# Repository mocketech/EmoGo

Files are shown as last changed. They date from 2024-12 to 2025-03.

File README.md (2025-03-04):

# EmoGo
A Go game system that conveys the state of Go stones through facial expressions

概要は以下の記事をご覧下さい。

Protopedia: [情碁 - 碁石の状態を表情で伝える囲碁ゲームシステム](https://protopedia.net/prototype/6237)

You can refer the following sites:
* Qiita: [XIAO RP2040でXIAO Round Displayを使う](https://qiita.com/mocketech/items/0c186354648cb941cb2cl) (in Japanese)
* [Seeed Studio XIAO RP2040 with Arduino](https://wiki.seeedstudio.com/XIAO-RP2040-with-Arduino/)
* [Getting Started with Seeed Studio Round Display for XIAO](https://wiki.seeedstudio.com/get_start_round_display/)
* Github: [MCP_CAN_lib](https://github.com/coryjfowler/MCP_CAN_lib)
* Waveshare: [2-CH CAN HAT](https://www.waveshare.com/wiki/2-CH_CAN_HAT)

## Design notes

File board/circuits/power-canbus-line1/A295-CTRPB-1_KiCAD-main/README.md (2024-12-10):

# A295-CTRPB-1_KiCAD
KiCAD library for A295-CTRPB-1

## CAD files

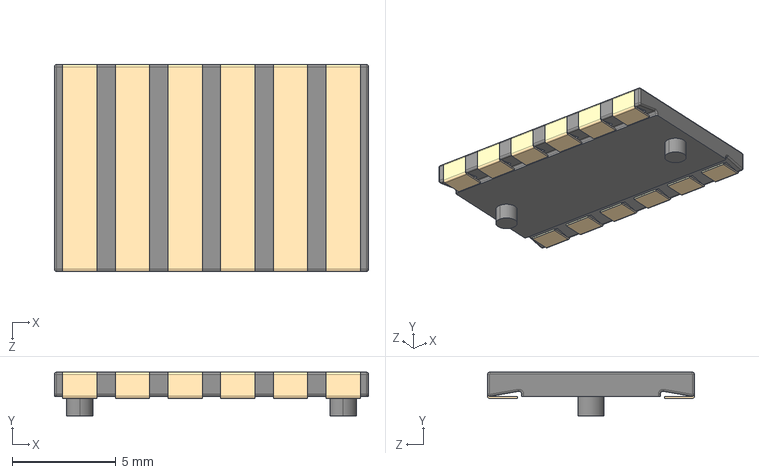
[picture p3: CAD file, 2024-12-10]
board/circuits/board/70AAJ-6-F1G/70AAJ-6-F1G.step
15.1 x 2.11 x 10.0 mm

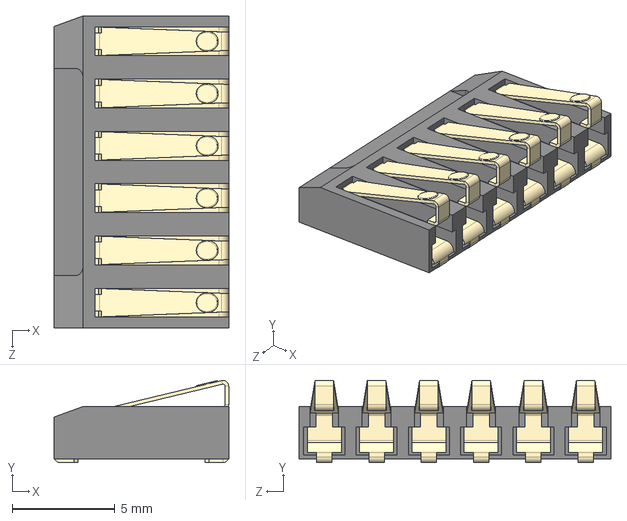
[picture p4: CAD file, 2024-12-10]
board/circuits/board/70AAJ-6-M0G/70AAJ-6-M0G.step
8.48 x 3.99 x 15.2 mm

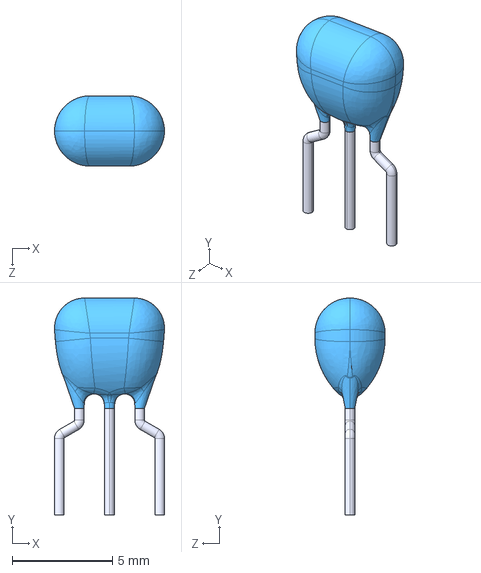
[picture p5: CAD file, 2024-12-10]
board/circuits/board/CSTLS20M0X51-B0/CSTLS20M0X51-B0.step
5.48 x 10.8 x 3.50 mm

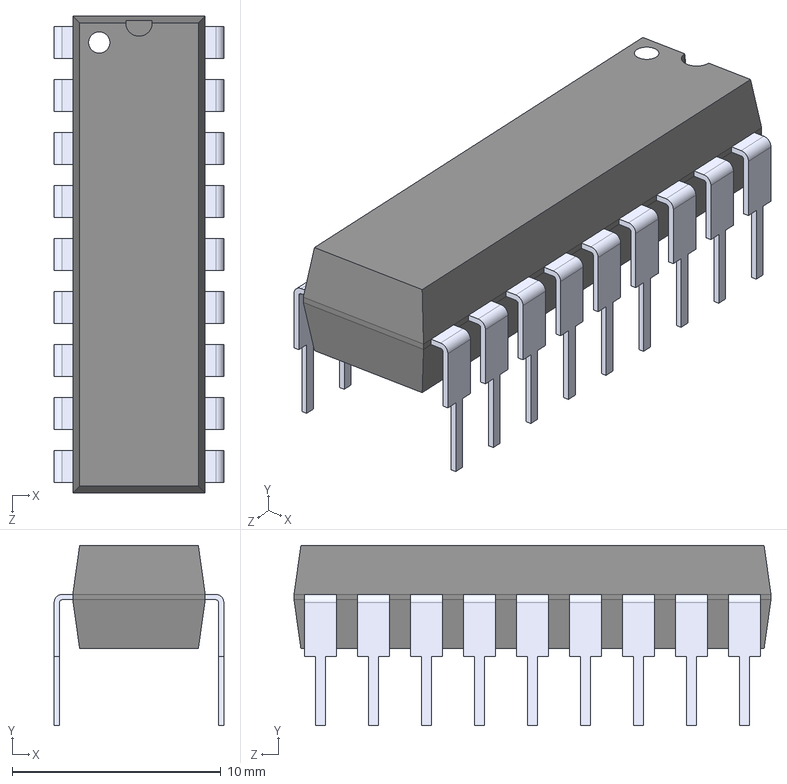
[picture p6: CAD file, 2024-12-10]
board/circuits/board/MCP2515-E_P/MCP2515-E_P.step
8.13 x 8.64 x 22.9 mm

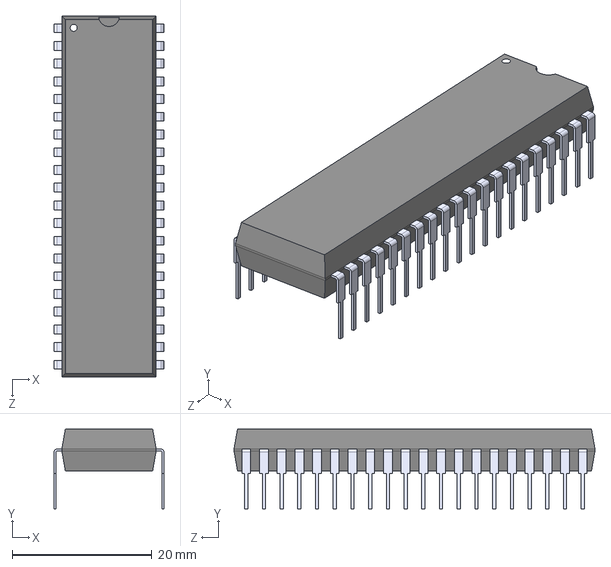
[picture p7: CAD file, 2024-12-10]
board/circuits/board/MCP2515-I_P/MCP2515-I_P.step
15.7 x 11.4 x 51.8 mm

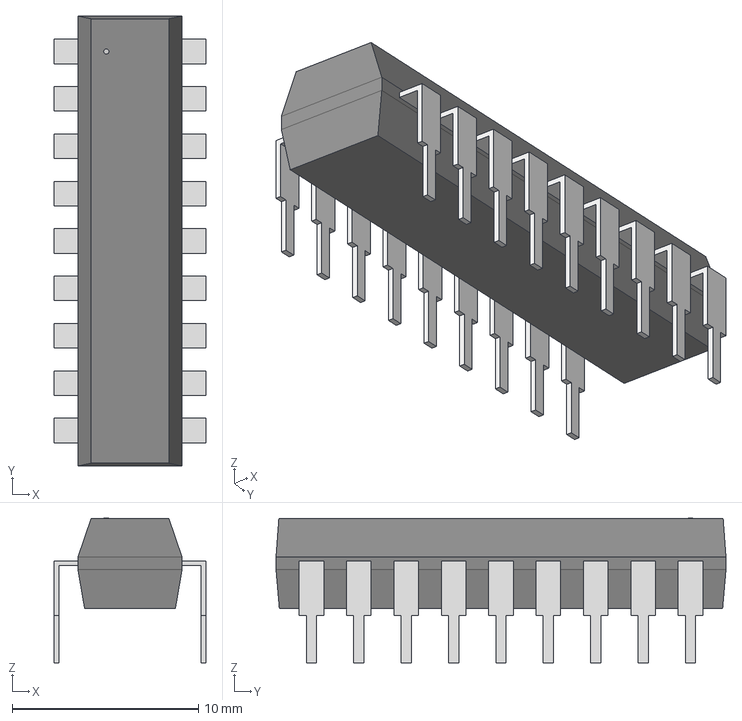
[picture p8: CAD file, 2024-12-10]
board/circuits/board/MCP2515_I_P/PDIP18_300MC_MCH.step
8.13 x 24.1 x 7.75 mm

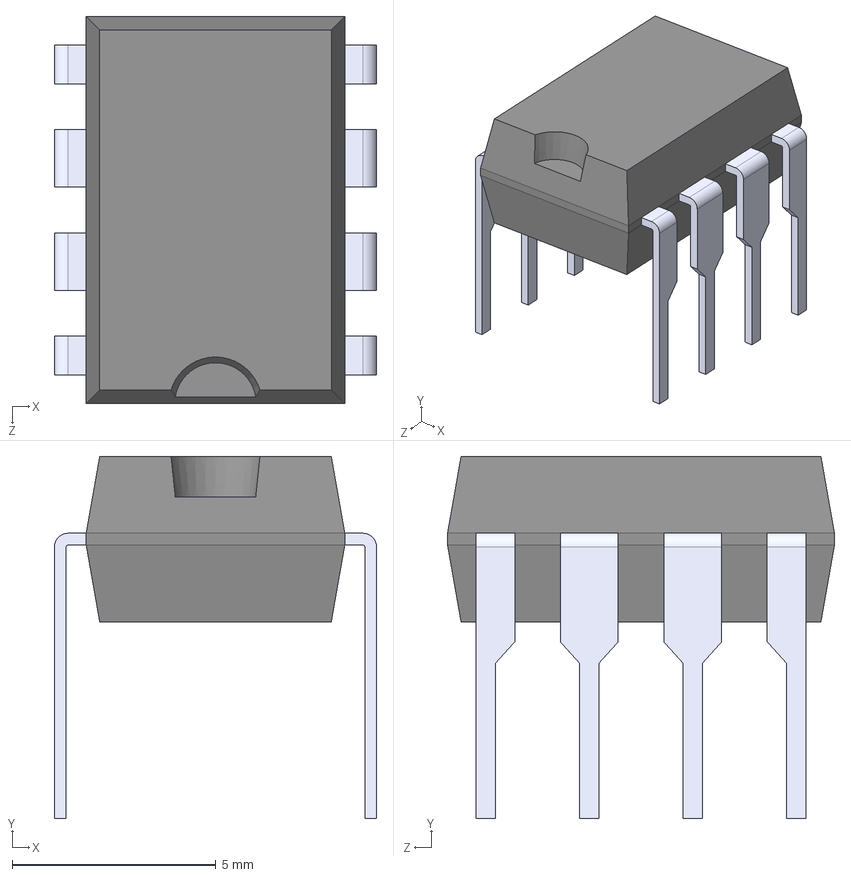
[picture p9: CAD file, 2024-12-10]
board/circuits/board/MCP2562-E_P/MCP2562-E_P.step
7.91 x 8.89 x 9.50 mm

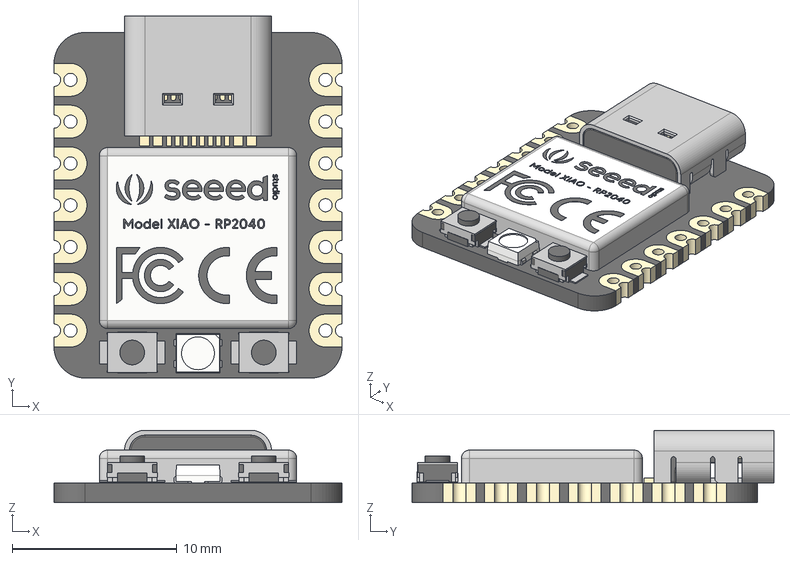
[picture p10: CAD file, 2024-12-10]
board/circuits/board/seeed-studio-xiao-rp2040-3d-model/Seeed Studio XIAO RP2040 v26.step
17.5 x 22.0 x 4.40 mm
type-c v2
smd_button v3
DOUT
DIN
VSS
VDD
smd_button v3(Mirror)

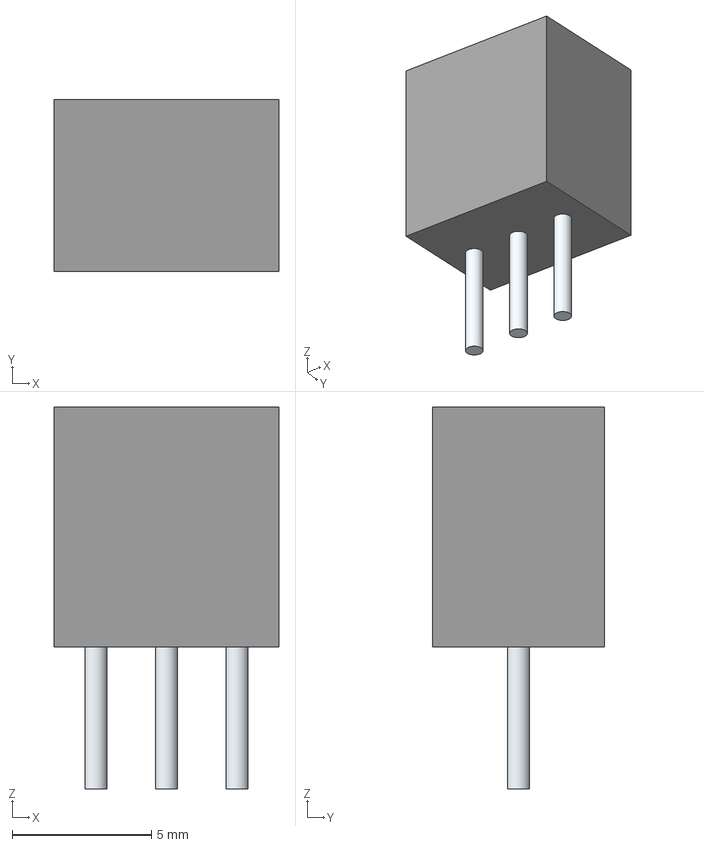
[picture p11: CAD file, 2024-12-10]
board/circuits/power-canbus-line1/LIB_WJEK254-2.54-03P-140-00A/WJEK254-2.54-03P-140-00A/3D/WJEK254-2.54-03P-140-00A.stp
8.08 x 6.20 x 13.7 mm
Leads

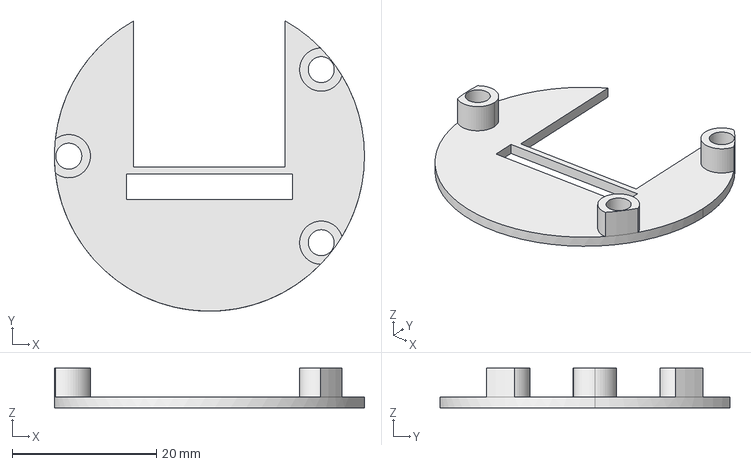
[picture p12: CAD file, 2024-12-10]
stone/3d_models/inner-plate/inner-plate.FCStd
43.0 x 40.3 x 5.50 mm

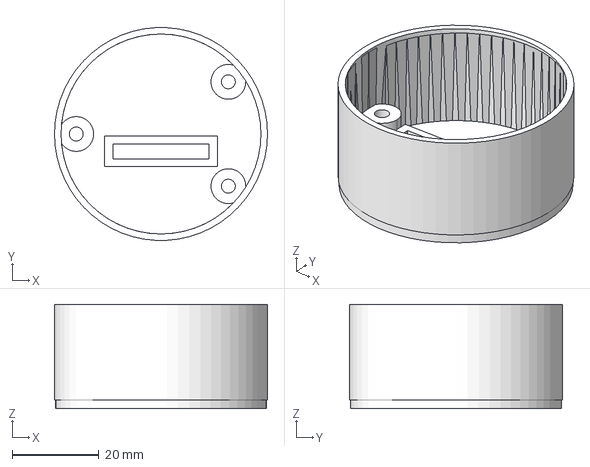
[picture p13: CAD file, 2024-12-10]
stone/3d_models/shell/shell.FCStd
49.0 x 48.9 x 24.0 mm
Tube

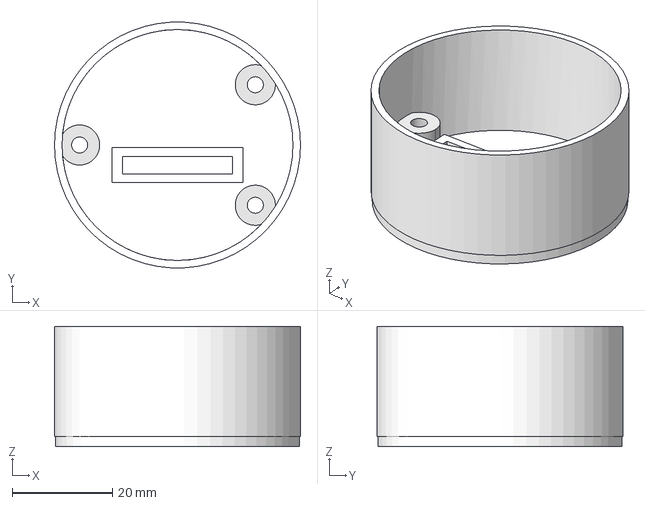
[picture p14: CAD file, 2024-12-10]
stone/3d_models/shell/shell-body.step
49.0 x 48.9 x 24.0 mm

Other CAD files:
stone/3d_models/inner-plate/inner-plate-body.step
board/circuits/board/seeed-studio-xiao-rp2040-3d-model/Seeed Studio XIAO RP2040 v26.f3d
board/circuits/power-canbus-line1/LIB_WJEK254-2.54-03P-140-00A/WJEK254-2.54-03P-140-00A/Allegro/wjek25425403p14000a.psm
board/circuits/power-canbus-line1/LIB_WJEK254-2.54-03P-140-00A/WJEK254-2.54-03P-140-00A/DEHDL/wjek254_2.54_03p_140_00a/chips/chips.prt
stone/3d_models/shell/shell-body.stl
stone/circuits/seeed-studio-xiao-rp2040-3d-model/Seeed Studio XIAO RP2040 v26.f3d

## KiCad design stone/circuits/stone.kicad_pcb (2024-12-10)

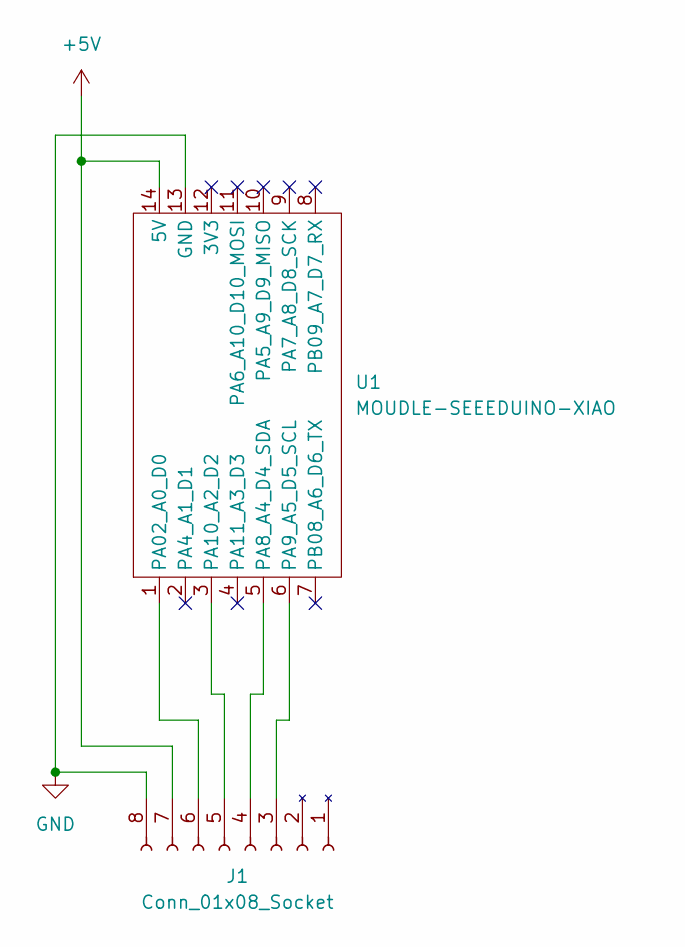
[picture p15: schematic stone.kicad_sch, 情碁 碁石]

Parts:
J1: Conn_01x08_Socket; PinSocket_1x08_P2.54mm_Vertical
U1: MOUDLE-SEEEDUINO-XIAO; MOUDLE14P-2.54-21X17.8MM

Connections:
+5V: J1.7, U1.14 (5V)
GND: J1.8, U1.13 (GND)
unnamed: J1.3, U1.6 (PA9_A5_D5_SCL)
unnamed: J1.4, U1.5 (PA8_A4_D4_SDA)
unnamed: J1.5, U1.3 (PA10_A2_D2)
unnamed: J1.6, U1.1 (PA02_A0_D0)

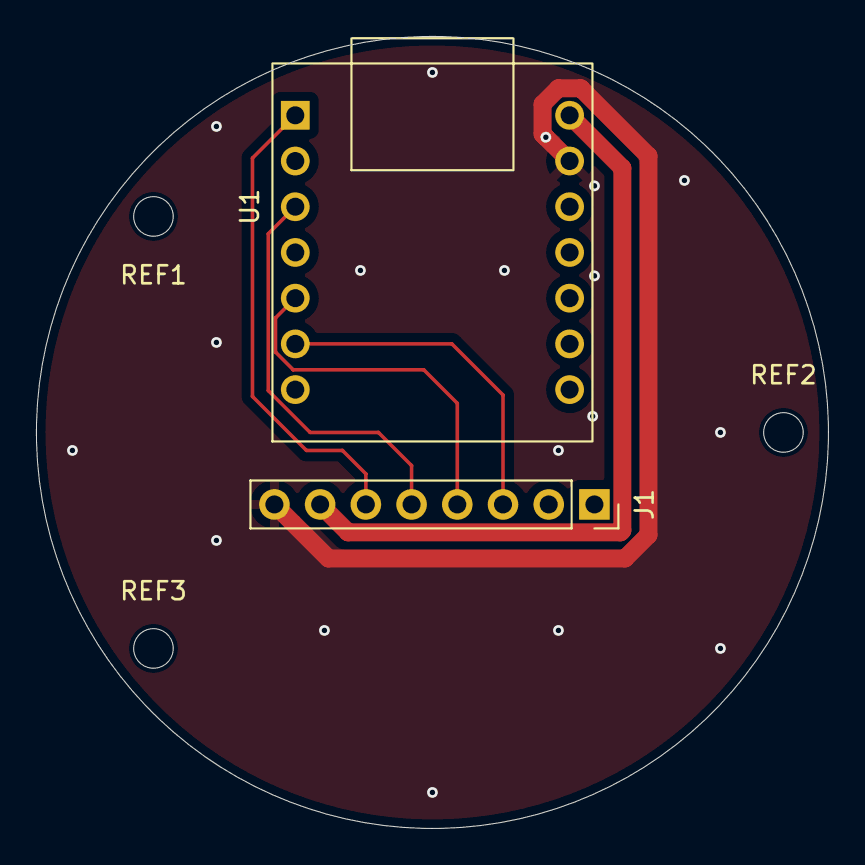
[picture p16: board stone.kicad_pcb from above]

Board: 2 copper layers, 44.0 x 44.0 mm, 5 parts (0 on the bottom side), 6 nets.

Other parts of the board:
REF1, REF2, REF3: MountingHole_2.2mm_M2

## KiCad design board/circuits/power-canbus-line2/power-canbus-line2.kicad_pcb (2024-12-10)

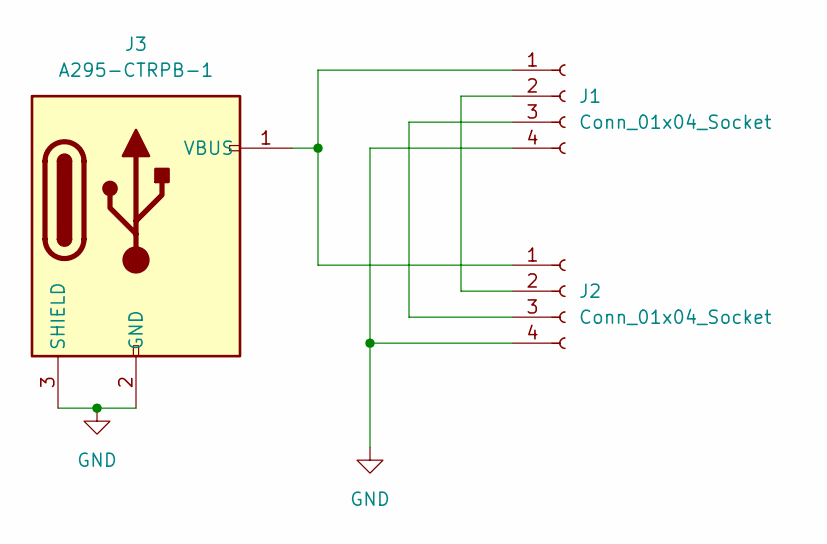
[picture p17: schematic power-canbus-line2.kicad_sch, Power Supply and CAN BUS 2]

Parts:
J1, J2: Conn_01x04_Socket; PinSocket_1x04_P2.54mm_Horizontal
J3: A295-CTRPB-1

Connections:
GND: J1.4, J2.4, J3.2 (GND), J3.3 (SHIELD)
unnamed: J1.1, J2.1, J3.1 (VBUS)
unnamed: J1.2, J2.2
unnamed: J1.3, J2.3

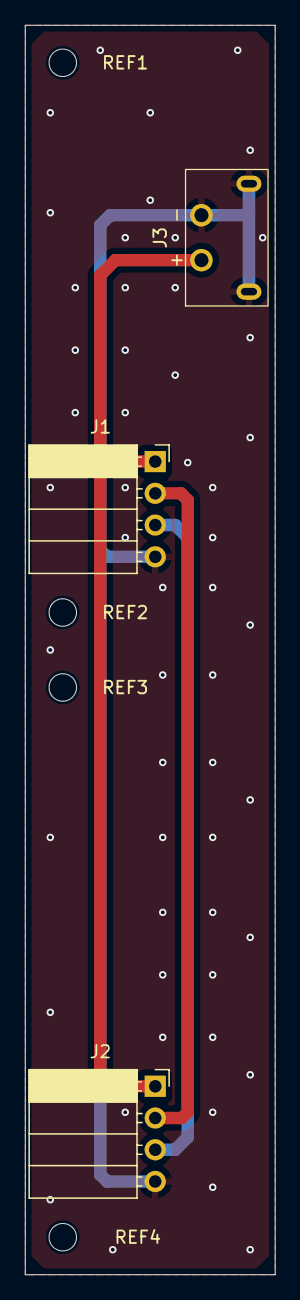
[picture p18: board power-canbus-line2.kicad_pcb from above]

Board: 2 copper layers, 20.0 x 100.0 mm, 7 parts (0 on the bottom side), 4 nets.

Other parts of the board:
REF1, REF2, REF3: MountingHole_2.2mm_M2_DIN965
REF4: MountingHole_2.2mm_M2

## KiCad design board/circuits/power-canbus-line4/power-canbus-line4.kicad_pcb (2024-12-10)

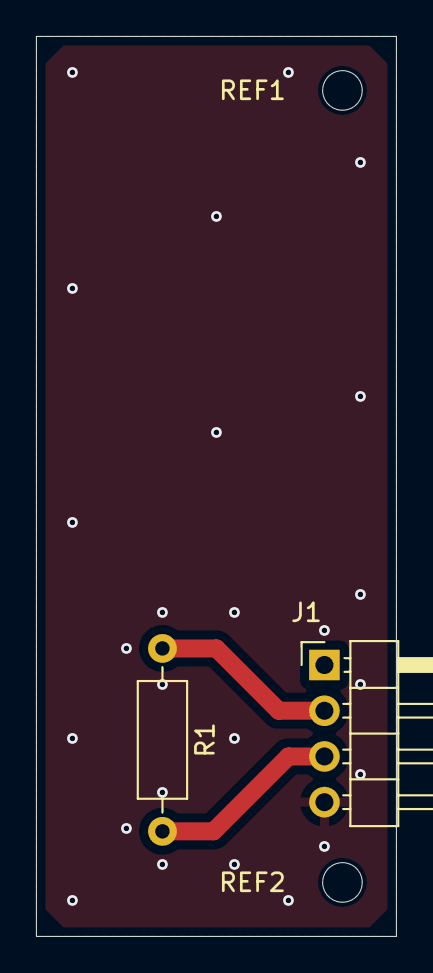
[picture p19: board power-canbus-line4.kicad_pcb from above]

Board: 2 copper layers, 20.0 x 50.0 mm, 4 parts (0 on the bottom side), 2 nets.

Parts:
J1: Conn_01x04_Pin; PinHeader_1x04_P2.54mm_Horizontal
R1: 120; R_Axial_DIN0207_L6.3mm_D2.5mm_P10.16mm_Horizontal
REF1, REF2: MountingHole_2.2mm_M2_DIN965

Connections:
unnamed: J1.2, R1.1
unnamed: J1.3, R1.2

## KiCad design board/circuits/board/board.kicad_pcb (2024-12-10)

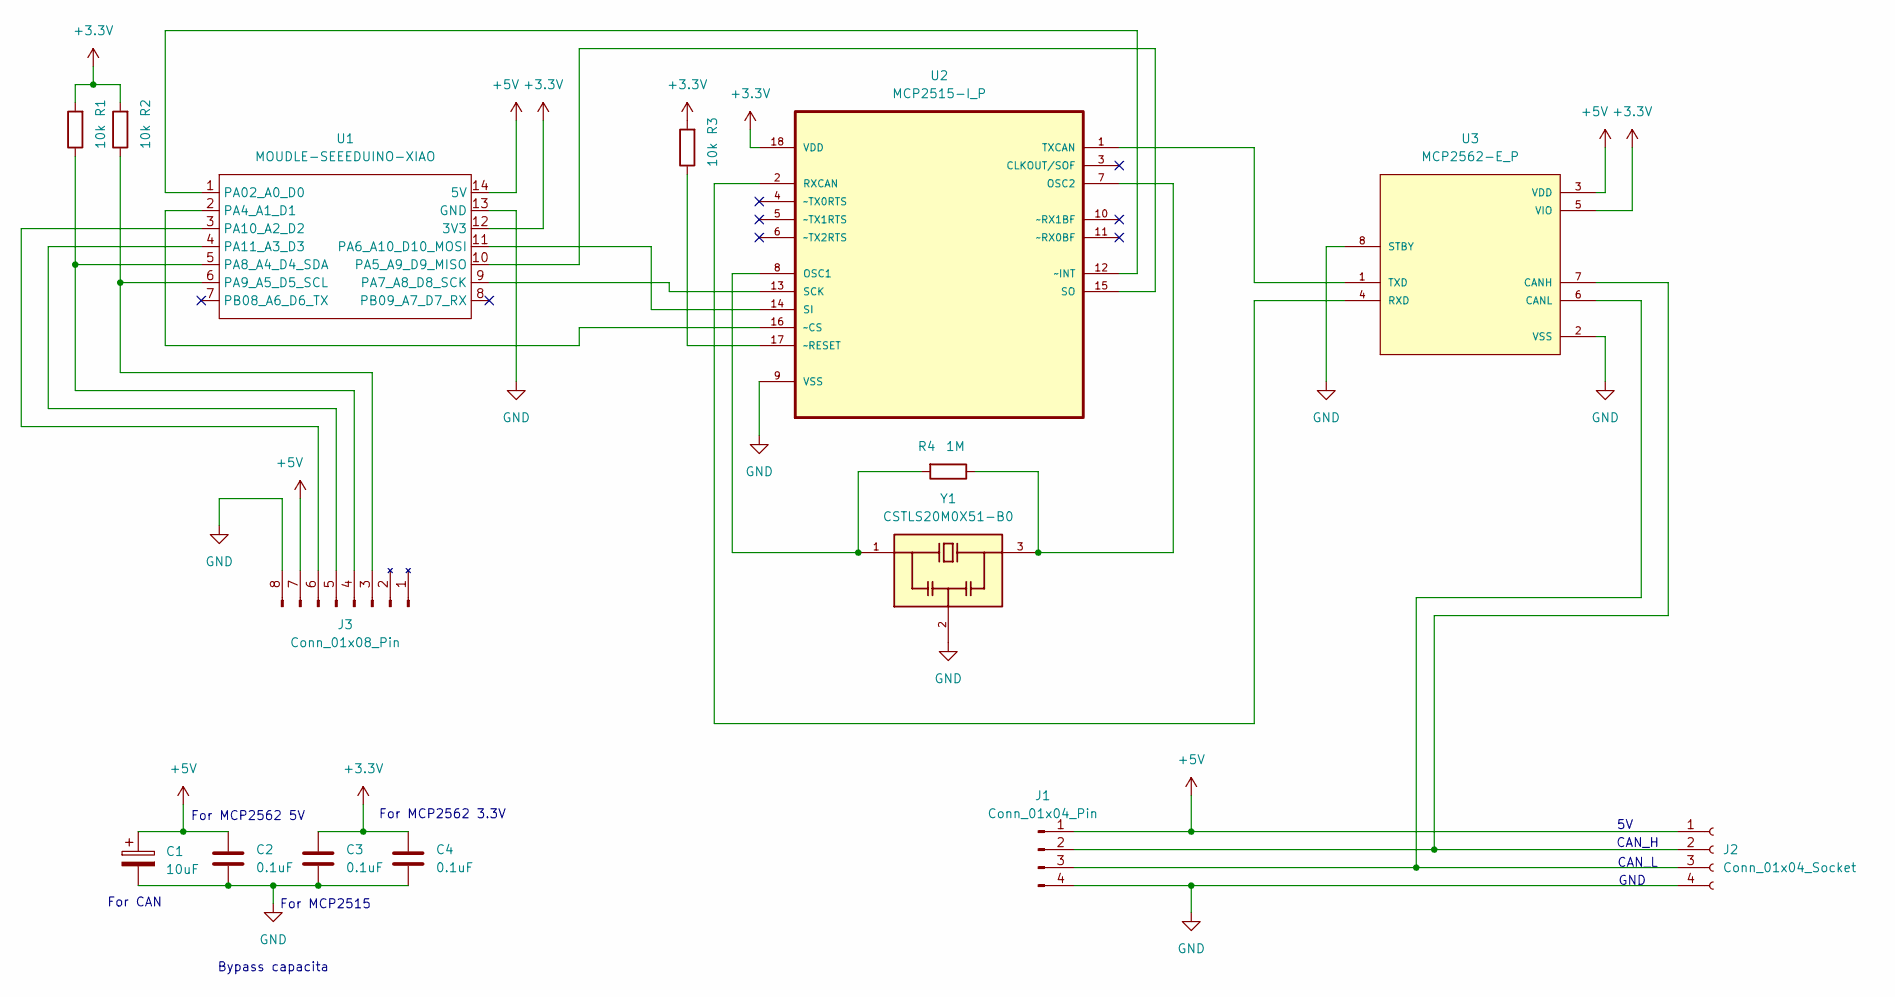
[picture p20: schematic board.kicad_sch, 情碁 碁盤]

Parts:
C1: 10uF; CP_Radial_D4.0mm_P1.50mm
C2, C3, C4: 0.1uF; C_Disc_D3.8mm_W2.6mm_P2.50mm
J1: Conn_01x04_Pin; PinHeader_1x04_P2.54mm_Horizontal
J2: Conn_01x04_Socket; PinSocket_1x04_P2.54mm_Horizontal
J3: Conn_01x08_Pin; PinHeader_1x08_P2.54mm_Vertical
R1, R2, R3: 10k; R_Axial_DIN0207_L6.3mm_D2.5mm_P10.16mm_Horizontal
R4: 1M; R_Axial_DIN0207_L6.3mm_D2.5mm_P10.16mm_Horizontal
U1: MOUDLE-SEEEDUINO-XIAO; MOUDLE14P-SMD-2.54-21X17.8MM
U2: MCP2515-I_P; DIP254P762X432-18; MPN MCP2515-I/P
U3: MCP2562-E_P; DIP787W45P254L1016H533Q8; PARTREV C
Y1: CSTLS20M0X51-B0; OSC_CSTLS20M0X51-B0; PARTREV March 23, 2017

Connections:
+3.3V: C3.1, C4.1, R1.2, R2.2, R3.2, U1.12 (3V3), U2.18 (VDD), U3.5 (VIO)
+5V: C1.1, C2.1, J1.1 (5V), J2.1 (5V), J3.7, U1.14 (5V), U3.3 (VDD)
GND: C1.2, C2.2, C3.2, C4.2, J1.4 (GND), J2.4 (GND), J3.8, U1.13 (GND), U2.9 (VSS), U3.2 (VSS), U3.8 (STBY), Y1.2
unnamed: J1.2 (CAN_H), J2.2 (CAN_H), U3.7 (CANH)
unnamed: J1.3 (CAN_L), J2.3 (CAN_L), U3.6 (CANL)
unnamed: J3.3, R2.1, U1.6 (PA9_A5_D5_SCL)
unnamed: J3.4, R1.1, U1.5 (PA8_A4_D4_SDA)
unnamed: J3.5, U1.4 (PA11_A3_D3)
unnamed: J3.6, U1.3 (PA10_A2_D2)
unnamed: U1.1 (PA02_A0_D0), U2.12 (~INT)
unnamed: U1.2 (PA4_A1_D1), U2.16 (~CS)
unnamed: U1.10 (PA5_A9_D9_MISO), U2.15 (SO)
unnamed: U1.11 (PA6_A10_D10_MOSI), U2.14 (SI)
unnamed: U1.9 (PA7_A8_D8_SCK), U2.13 (SCK)
unnamed: R4.2, U2.8 (OSC1), Y1.1
unnamed: R4.1, U2.7 (OSC2), Y1.3
unnamed: U2.2 (RXCAN), U3.4 (RXD)
unnamed: U2.1 (TXCAN), U3.1 (TXD)
unnamed: R3.1, U2.17 (~RESET)

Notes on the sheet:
For CAN
For MCP2515
For MCP2562 3.3V
GND
Bypass capacita
CAN_H
CAN_L
For MCP2562 5V

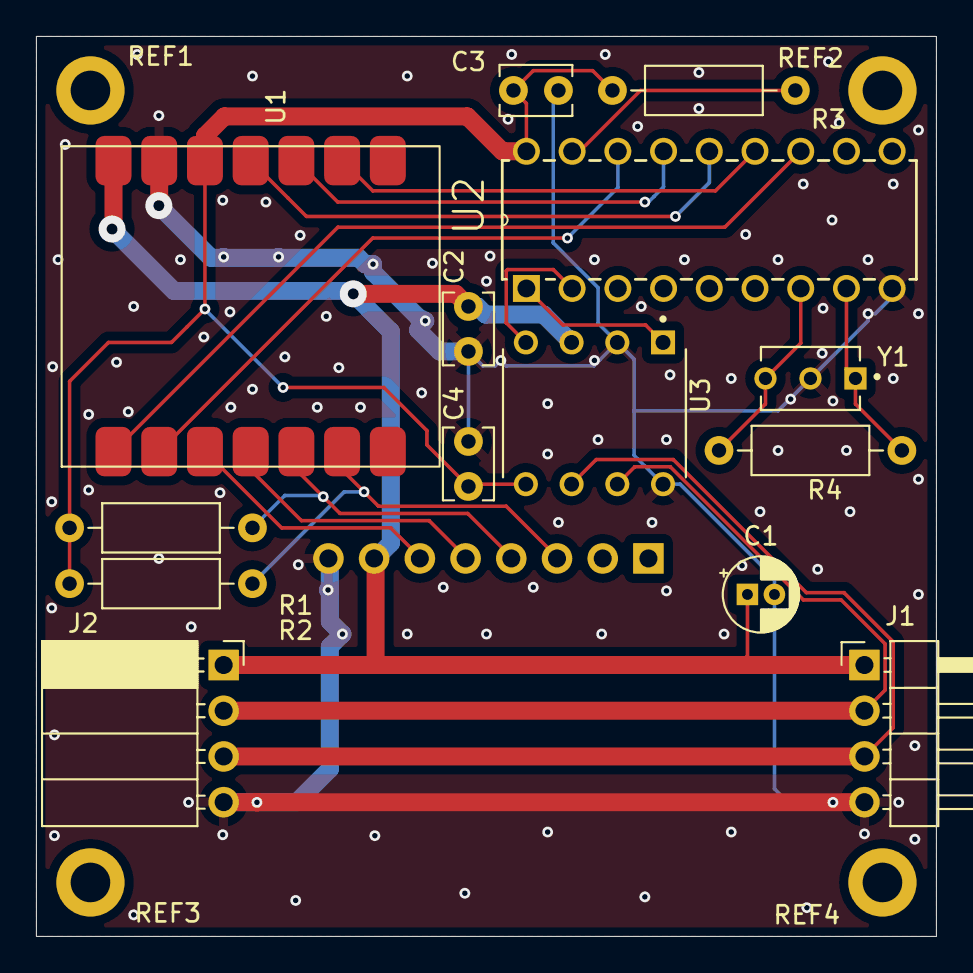
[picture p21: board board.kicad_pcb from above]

Board: 2 copper layers, 50.0 x 50.0 mm, 19 parts (1 on the bottom side), 19 nets.

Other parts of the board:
REF1, REF2, REF3, REF4: MountingHole_2.2mm_M2_DIN965_Pad

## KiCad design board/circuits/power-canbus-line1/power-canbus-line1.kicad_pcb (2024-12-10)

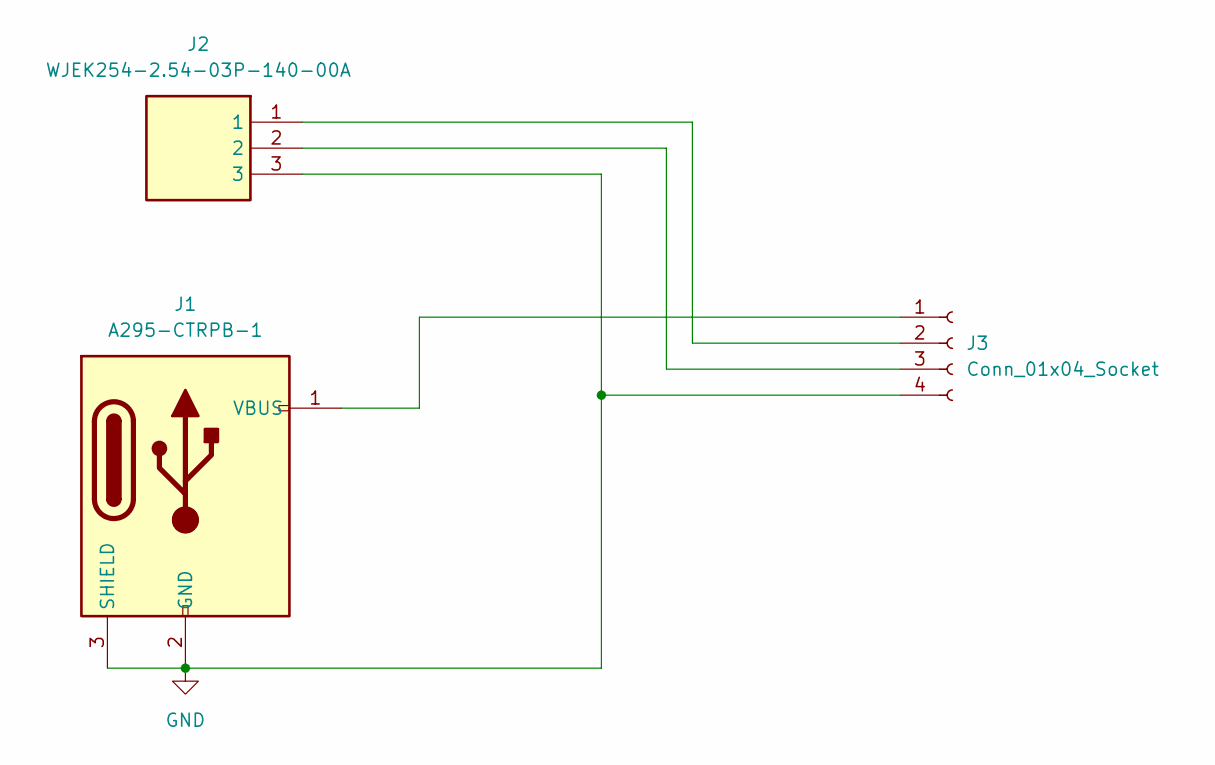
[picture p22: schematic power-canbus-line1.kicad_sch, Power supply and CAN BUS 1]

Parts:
J1: A295-CTRPB-1
J2: WJEK254-2.54-03P-140-00A; WJEK25425403P14000A; Manufacturer_Part_Number WJEK254-2.54-03P-140-00A
J3: Conn_01x04_Socket; PinSocket_1x04_P2.54mm_Horizontal

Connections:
GND: J1.2 (GND), J1.3 (SHIELD), J2.3, J3.4
unnamed: J1.1 (VBUS), J3.1
unnamed: J2.1, J3.2
unnamed: J2.2, J3.3

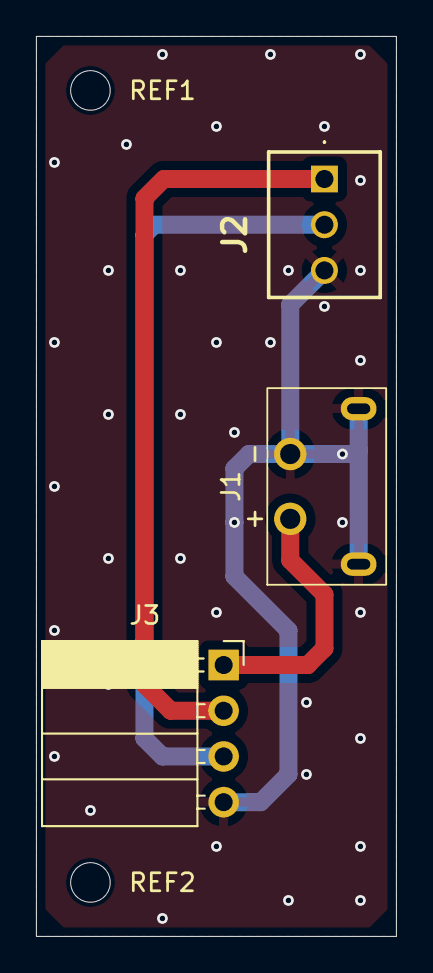
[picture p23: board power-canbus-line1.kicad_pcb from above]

Board: 2 copper layers, 20.0 x 50.0 mm, 5 parts (0 on the bottom side), 4 nets.

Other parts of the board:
REF1, REF2: MountingHole_2.2mm_M2_DIN965

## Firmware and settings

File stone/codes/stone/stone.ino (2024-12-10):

#include <Wire.h>

#include "xiao_round_display.hpp"
#include "data/dead_blink.h"
#include "data/dead_black.h"
#include "data/dead_white.h"
#include "data/defensive_blink.h"
#include "data/defensive_black.h"
#include "data/defensive_white.h"
#include "data/normal_blink.h"
#include "data/normal_black.h"
#include "data/normal_white.h"
#include "data/offensive_blink.h"
#include "data/offensive_black.h"
#include "data/offensive_white.h"

const uint8_t *image[][4] = { 
  { 
    dead_blink_png, defensive_blink_png, normal_blink_png, offensive_blink_png,
  }, {
    dead_black_png, defensive_black_png, normal_black_png, offensive_black_png,
  }, {
    dead_white_png, defensive_white_png, normal_white_png, offensive_white_png,
  }
};

const uint32_t image_len[][4] = {
  {
    dead_blink_png_len, defensive_blink_png_len, normal_blink_png_len, offensive_blink_png_len, 
  }, {
    dead_black_png_len, defensive_black_png_len, normal_black_png_len, offensive_black_png_len,
  }, {
    dead_white_png_len, defensive_white_png_len, normal_white_png_len, offensive_white_png_len,    
  }
};

XiaoRoundDisplay display;
LGFX_Sprite sprite_main( &display), sprite_blink( &display);

// 碁石の色
#define STONE_BLINK 0
#define STONE_BLACK 1
#define STONE_WHITE 2


// 碁石の表情
#define STONE_DEAD      0
#define STONE_DEFENSIVE 1
#define STONE_NORMAL    2
#define STONE_OFFENSIVE 3

// 碁石の向き
#define STONE_NORTH 0
#define STONE_EAST  90
#define STONE_SOUTH 180
#define STONE_WEST  270

// 碁石の状態
uint32_t stone_color = STONE_BLACK;
uint32_t stone_emotion = STONE_NORMAL;
uint32_t stone_direction = STONE_NORTH;
bool    stone_blink_state = false;
bool    stone_blink_expression = false;

// 外部通信定義
#define STONE_PWR D0
#define STONE_INT D2
#define TOUCH_INT D7
#define I2C_ADDR 0x8
uint8_t i2c_rxbuf[ 5] = { 0x00, 0x00, 0x00, 0x00, 0x00};
uint8_t i2c_txbuf[ 2] = { 0x00, 0x00};
bool i2c_recv_interrupted = false;
bool i2c_send_interrupted = false;
bool touch_interrupted = false;
uint32_t touch_timer = 0;

#define SET_STATE     1
#define SET_BLINK     2
#define BLINK         3

HardwareSerial *uart;

void receiveEvent( int num) {
  i2c_recv_interrupted = true;
  uart->println( "enter receiveEvent function.");
  
  for ( uint32_t i = 0; Wire.available(); i++) {
    if ( i < 5) i2c_rxbuf[ i] = Wire.read();
    else Wire.read();
  }
}

void sendEvent() {
  i2c_send_interrupted = true;
  
  for ( uint32_t i = 0; i < 2; i++) {
    Wire.write( i2c_txbuf[ i]);
  }
}

void touchEvent() {
  if ( touch_timer < millis()) {
    digitalWrite( STONE_INT, LOW);
    uart->println( "Touch Event " + String(millis()));
    touch_timer = millis() + 100;
  } else {
    digitalWrite( STONE_INT, HIGH);
  }
}

void setup() {
  uart = &Serial;
  //uart = &Serial1;
  
  uart->begin( 9600);
  delay( 1000);
  uart->println( "start:");

  // I2C settings
  Wire.begin( I2C_ADDR);
  //pinMode( SDA, INPUT);
  //pinMode( SCL, INPUT);
  Wire.onReceive( receiveEvent);
  Wire.onRequest( sendEvent);
  uart->println( "I2C settings done.");

  // Notify power and touch
  pinMode( STONE_PWR, OUTPUT);
  digitalWrite( STONE_PWR, LOW);
  pinMode( STONE_INT, OUTPUT);
  digitalWrite( STONE_INT, HIGH);
  pinMode( TOUCH_INT, INPUT_PULLUP);
  attachInterrupt( TOUCH_INT, touchEvent, FALLING);
  
  // Display settings
  display.init();
  sprite_main.createSprite( 120, 120);
  sprite_blink.createSprite( 120, 120);
  
  //sprite_main.drawPng( image[ stone_color][ stone_emotion], image_len[ stone_color][ stone_emotion], 0, 0);
  //sprite_blink.drawPng( image[ STONE_BLINK][ stone_emotion], image_len[ STONE_BLINK][ stone_emotion], 0, 0);
  
  display.startWrite();
  display.clear();
  //sprite_main.pushRotateZoom( 0, 2, 2);
  display.endWrite();
}

void loop() {
  String dbgMsg;
  
  if ( i2c_recv_interrupted) {
    i2c_recv_interrupted = false;
    dbgMsg = "command, parameters = " + String( i2c_rxbuf[ 0], HEX);
    for ( uint32_t i = 1; i <= 4; i++) {
      dbgMsg += ", " + String( i2c_rxbuf[ i], HEX); 
    }
    uart->println( dbgMsg);
        
    switch ( i2c_rxbuf[ 0]) {
      case SET_STATE:
      stone_color = i2c_rxbuf[ 1];
      stone_emotion = i2c_rxbuf[ 2];
      stone_direction = (uint32_t)i2c_rxbuf[ 3] * 256 + i2c_rxbuf[ 4];
      uart->println( String(stone_color)+" "+String(stone_emotion)+" "+String(stone_direction));
      break;
      
      case SET_BLINK:
      stone_blink_state = ( i2c_rxbuf[ 1] != 0x00) ? true : false;
      stone_blink_expression = false;
      break;
      
      case BLINK:
      if ( stone_blink_state) stone_blink_expression = ( i2c_rxbuf[ 1] != 0x00) ? true : false;
      else stone_blink_expression = false;
      break;
    }

    if ( stone_blink_state) {
      display.startWrite();
      if ( stone_blink_expression) sprite_blink.pushRotateZoom( stone_direction, 2.0, 2.0);
      else sprite_main.pushRotateZoom( stone_direction, 2.0, 2.0);
      display.endWrite();
      
    } else {
      sprite_main.drawPng( image[ stone_color][ stone_emotion], image_len[ stone_color][ stone_emotion], 0, 0);
      sprite_blink.drawPng( image[ STONE_BLINK][ stone_emotion], image_len[ STONE_BLINK][ stone_emotion], 0, 0);
      display.startWrite();
      sprite_main.pushRotateZoom( stone_direction, 2.0, 2.0);
      display.endWrite();
    }
  }

  if ( touch_interrupted) {
    touch_interrupted = false;
  }
}

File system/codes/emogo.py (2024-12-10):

import threading
import time
import can
import sys

class Stone:
    # 定数の定義
    COLOR_VALUES = {
        'black': 0x01,
        'white': 0x02
    }

    DIRECTION_VALUES = {
        'north': 90,
        'east': 180,
        'south': 270,
        'west': 0
    }

    EMOTION_VALUES = {
        'dead': 0,
        'defensive': 1,
        'normal': 2,
        'offensive': 3
    }

    def __init__(self):
        self.color = None
        self.direction = self.DIRECTION_VALUES['north']
        self.emotion = self.EMOTION_VALUES['normal']

    # 色を設定するメソッド
    def set_color(self, color):
        if color in self.COLOR_VALUES:
            self.color = self.COLOR_VALUES[color]
        elif color in self.COLOR_VALUES.values():
            self.color = color
        else:
            raise ValueError("Invalid color")

    # 色を取得するメソッド
    def get_color(self):
        return self.color or 0x00  # 0x00 は石がないことを示す

    # 向きを設定するメソッド
    def set_direction(self, direction):
        if direction in self.DIRECTION_VALUES:
            self.direction = self.DIRECTION_VALUES[direction]
        elif direction in self.DIRECTION_VALUES.values():
            self.direction = direction
        else:
            raise ValueError("Invalid direction")

    # 向きを取得するメソッド
    def get_direction(self):
        return self.direction or 0

    # 感情を設定するメソッド
    def set_emotion(self, emotion):
        if emotion in self.EMOTION_VALUES:
            self.emotion = self.EMOTION_VALUES[emotion]
        elif emotion in self.EMOTION_VALUES.values():
            self.emotion = emotion
        else:
            raise ValueError("Invalid emotion")

    # 感情を取得するメソッド
    def get_emotion(self):
        return self.emotion or self.EMOTION_VALUES['dead']

class Board:
    def __init__(self, n, m):
        self.n = n  # 行数
        self.m = m  # 列数
        self.board = [[None for _ in range(m)] for _ in range(n)]  # [行][列] の順序
        self.connect = []

    # 石を置くメソッド
    def place_stone(self, x, y, color):
        if 1 <= x <= self.n and 1 <= y <= self.m:
            ix = x - 1  # 行インデックス
            iy = y - 1  # 列インデックス
            if self.board[ix][iy] is None:
                stone = Stone()
                stone.set_color(color)
                stone.set_direction('north')
                stone.set_emotion('normal')
                self.board[ix][iy] = stone
                # ここで死に石判定を行う
                self.check_dead_stones_after_placement(x, y, color)
            else:
                raise RuntimeError(f"Position ({x}, {y}) already has a stone")
        else:
            raise IndexError(f"Position ({x}, {y}) is out of bounds")

    # 石を取り除くメソッド
    def remove_stone(self, x, y):
        if 1 <= x <= self.n and 1 <= y <= self.m:
            ix = x - 1  # 行インデックス
            iy = y - 1  # 列インデックス
            if self.board[ix][iy] is not None:
                self.board[ix][iy] = None
            else:
                raise RuntimeError(f"No stone at position ({x}, {y}) to remove")
        else:
            raise IndexError(f"Position ({x}, {y}) is out of bounds")

    # 石を取得するメソッド
    def get_stone(self, x, y):
        if 1 <= x <= self.n and 1 <= y <= self.m:
            ix = x - 1  # 行インデックス
            iy = y - 1  # 列インデックス
            return self.board[ix][iy]
        else:
            raise IndexError(f"Position ({x}, {y}) is out of bounds")

    # 死に石判定を行うメソッド
    def check_dead_stones_after_placement(self, x, y, color):
        opponent_color = 'white' if color == 'black' else 'black'

        # 1. 相手の死に石を判定し、感情を 'dead' に設定
        opponent_dead_stones = self.find_dead_stones(opponent_color)
        for ix, iy in opponent_dead_stones:
            stone = self.board[ix][iy]
            if stone:
                stone.set_emotion('dead')

        # 2. 自分の死に石を判定し、感情を 'dead' に設定
        self_dead_stones = self.find_dead_stones(color)
        for ix, iy in self_dead_stones:
            stone = self.board[ix][iy]
            if stone:
                stone.set_emotion('dead')

        # 3. 繋がりと感情の更新
        self.check_connect()

    # 死に石を見つけるメソッド
    def find_dead_stones(self, color):
        visited = [[False for _ in range(self.m)] for _ in range(self.n)]
        dead_stones = []

        for ix in range(self.n):
            for iy in range(self.m):
                if visited[ix][iy]:
                    continue
                stone = self.board[ix][iy]
                if stone is None or stone.get_color() != Stone.COLOR_VALUES[color]:
                    continue
                group, liberties = self.dfs(ix, iy, color, visited)
                if liberties == 0:
                    dead_stones.extend(group)
        return dead_stones

    # 深さ優先探索でグループと呼吸点を計算
    def dfs(self, ix, iy, color, visited):
        stack = [(ix, iy)]
        group = []
        liberties = set()  # 呼吸点をセットで管理
        visited[ix][iy] = True

        while stack:
            x, y = stack.pop()
            group.append((x, y))

            neighbors = [
                (x - 1, y),  # 上
                (x + 1, y),  # 下
                (x, y - 1),  # 左
                (x, y + 1)   # 右
            ]

            for nx, ny in neighbors:
                if 0 <= nx < self.n and 0 <= ny < self.m:
                    neighbor_stone = self.board[nx][ny]
                    if neighbor_stone is None or neighbor_stone.get_emotion() == Stone.EMOTION_VALUES['dead']:
                        liberties.add((nx, ny))  # 呼吸点をセットに追加
                    elif neighbor_stone.get_color() == Stone.COLOR_VALUES[color] and not visited[nx][ny]:
                        visited[nx][ny] = True
                        stack.append((nx, ny))
        return group, len(liberties)

    # 連のためのDFS（死に石も含む）
    def dfs_for_connect(self, ix, iy, color, visited):
        stack = [(ix, iy)]
        group = []
        liberties = set()
        visited[ix][iy] = True

        while stack:
            x, y = stack.pop()
            group.append((x, y))

            neighbors = [
                (x - 1, y),  # 上
                (x + 1, y),  # 下
                (x, y - 1),  # 左
                (x, y + 1)   # 右
            ]

            for nx, ny in neighbors:
                if 0 <= nx < self.n and 0 <= ny < self.m:
                    if not visited[nx][ny]:
                        neighbor_stone = self.board[nx][ny]
                        if neighbor_stone is not None and neighbor_stone.get_color() == color:
                            visited[nx][ny] = True
                            stack.append((nx, ny))
                        elif neighbor_stone is None or neighbor_stone.get_emotion() == Stone.EMOTION_VALUES['dead']:
                            liberties.add((nx, ny))
        return group, len(liberties)

    # 連と感情を再計算するメソッド
    def check_connect(self):
        self.connect = []
        visited = [[False for _ in range(self.m)] for _ in range(self.n)]
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
